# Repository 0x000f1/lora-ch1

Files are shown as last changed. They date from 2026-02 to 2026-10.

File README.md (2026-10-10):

# lora-ch1

This project is based on the ESP32-C3 microcontroller that behaves like a bridge between mobile devices and the modules. The connection is established via Bluetooth Low Energy with the phone, then sends the package over the LoRa (RFM98W/SX1278) module at 433 MHz. This combination is able to perform a full internet-independent communication between two or more devices, at a long range.

## Hardware Specification & Pinout

The current hardware is based on the ESP32-C3 microcontroller, interfaced with an RFM98W/SX1278 LoRa module, a DRV2605L haptic driver, and a BQ24075 based charging circuit.

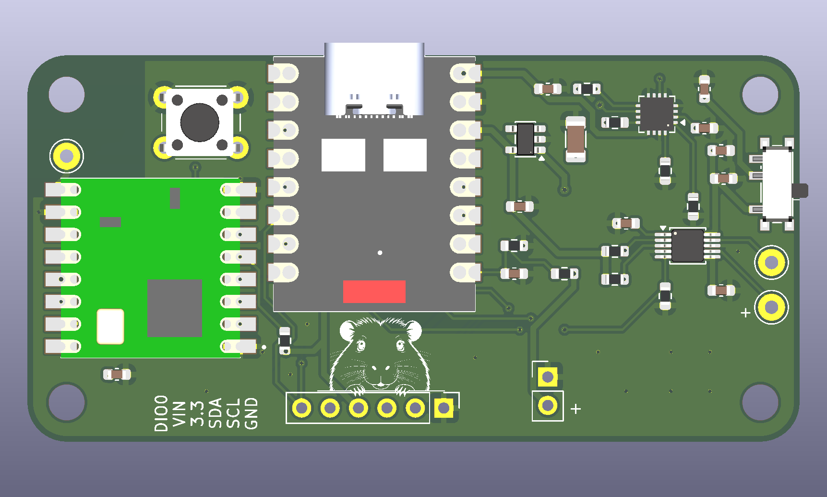
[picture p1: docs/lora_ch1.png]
PCB Layout


### ESP32-C3 GPIO Mapping

| Component | Pin Name | ESP32-C3 GPIO | Description |
| :--- | :--- | :--- | :--- |
| **LoRa (SPI)** | MISO | GPIO 5 | Master In Slave Out |
| | MOSI | GPIO 6 | Master Out Slave In |
| | NSS | GPIO 7 | Chip Select (CS) |
| | SCK | GPIO 4 | SPI Clock |
| | DIO1 | GPIO 3 | IRQ / Interrupt 1 |
| | DIO0 | GPIO 10 | IRQ / Interrupt 0 |
| | RST | GPIO 2 | LoRa Reset |
| **I2C Bus** | SDA | GPIO 8 | I2C Data (DRV2605L) |
| | SCL | GPIO 9 | I2C Clock (DRV2605L) |
| **Haptic Driver** | DRV_EN | GPIO 21 | Enable pin for DRV2605L |
| **Power / Battery** | CHRG | GPIO 20 | Charging status (BQ24075, LOW = charging) |
| | BAT_SENS | GPIO 1 | Battery Voltage ADC (ADC_11db attenuation) |
| **User Input** | BUTTON | GPIO 0 | Hardware Button (with debouncing) |

### Development Environment & Flashing
* **IDE:** **PlatformIO**
* **Board:** **`esp32-c3-devkitm-1`**

## Functions

* **Reliable Bidirectional Communication:** Transmit packages seamlessly between two or more devices. Supports public Broadcasts and private P2P messages with an Automatic Repeat Request (ARQ) mechanism. P2P messages are automatically acknowledged (ACK) and retried up to 3 times if lost in the air.
* **Fast TX & Continuous RX Architecture:** Optimized for ultra-low latency and high reliability in the prototype phase. By utilizing an optimized preamble (12 symbols), the Time on Air (ToA) is reduced to ~100-132ms (payload dependent), virtually eliminating packet collisions while ensuring zero message drops through continuous background listening. *Thread-safe FreeRTOS implementation prevents conflicts between BLE and LoRa tasks*.
* **End-to-End Encryption Support (Key Exchange):** Natively supports routing public keys for E2EE via `KEY_REQ` and `KEY_RESP` commands over the standard data characteristic. The key exchange utilizes the existing ARQ (Hardware ACK) mechanism ensuring reliable and verified key delivery between peers.
* **Offline Message Buffer:** Safely stores up to 32 incoming direct (P2P) messages in the RAM if the phone is disconnected. Upon BLE reconnection, all buffered messages are instantly pushed to the app. Public Broadcasts are ignored for offline storage to preserve memory.
* **Smart Neighbour Discovery:** Automatic heartbeat messages are sent out to advertise the active device among other users, storing the RSSI, last active timestamp, and the user's custom RGB UI color. The system automatically cleans up "dead" or out-of-range nodes after a timeout period based on the active power profile.
* **Location Sharing & Privacy:** Broadcasts the user's GPS coordinates (Latitude and Longitude) to the mesh network via Heartbeat messages. If the user disables location sharing (Privacy Mode), the system dynamically truncates the binary payload by 8 bytes to conserve precious LoRa airtime and battery life.
* **Haptic & UI Feedback:** Integrated DRV2605L haptic motor driver and hardware button with debouncing. Provides distinct physical feedback for button presses, incoming LoRa messages, and an automatic low battery warning (triggered below 15% while discharging).
* **BLE Security (Just Works):** Implements physical button-press validation to activate BLE advertising (Pairing Mode) for 60 seconds, preventing unauthorized external connections.
* **Dynamic NVS Management:** The device name, UUIDs, unique LoRa ID, haptic profile, and user preferences (Username, UI Color, Location) are generated on the first startup and safely stored in the Non-Volatile Storage (NVS).
* **Duty Cycle Monitoring:** Tracks and logs the Time on Air (ToA) and calculates the current duty cycle percentage to assist with regulatory compliance (e.g., the 10% limit on 433MHz in Europe).
* **Automated Power Management:** Supports 3 different power profiles (`BATTERY_SAVER`, `BALANCED`, `PERFORMANCE`) that dynamically scale the CPU frequency (80MHz or 160MHz) and adjust heartbeat intervals (10 min, 5 min, and 1 min respectively). The device defaults to `BATTERY_SAVER` on boot. Pressing the hardware button temporarily wakes the system into `BALANCED` mode for BLE communication.
* **Real Battery Monitoring:** Built-in hardware ADC integration calculates real battery percentage, and monitors the active charging status via the BQ24075 charging IC's open-drain output (GPIO 20).

## BLE API Documentation

The mobile app connects to the ESP32 and manages the LoRa module (and some settings).

### 1. Discovering the device (Scanning & Connection)

* **IMPORTANT (MTU Size):** The Android application **MUST** request an MTU size of 512 bytes (`requestMtu(512)`) immediately after the connection is established. Without this, Android will truncate incoming messages to 20 bytes! iOS handles this automatically.
* **Device Name:** The ESP32 starts advertising in this format `lora-ch1-XXXX` where the `XXXX` is the device's MAC address's last 2 bytes (e.g., `lora-ch1-A1B2`).
* **Dynamic UUIDs:** **IMPORTANT!** On the first start, the device generates (Version 4) UUIDs for the services and characteristics. The mobile device should use **Service Discovery** instead of hardcoded UUIDs!
* **Pairing Mode:** The device is hidden by default. Press the physical button on the device to enable Bluetooth visibility for 60 seconds.

### 2. Services and characteristics

The system advertises a single main Service, under which two characteristics (Data and Control) are located. Both characteristics support `READ`, `WRITE`, and `NOTIFY` operations.

#### A. Data Characteristic
Actual message sending and receiving takes place on this channel. The payload must follow a semicolon-separated format to support message fragmentation and direct addressing.

* **Sending (App -> LoRa):**
  * **Format 1 (Standard Message):** `TARGET_MAC;CURRENT_FRAGMENT;TOTAL_FRAGMENTS;PAYLOAD`
    * Write a String to this characteristic using the format above.
    * *Target MAC:* 8-character HEX string. Use `FFFFFFFF` to Broadcast to everyone, or a specific device's LoRa ID for a private P2P message.
    * *Example (Broadcast):* `FFFFFFFF;1;1;Hello everyone!`
    * *Example (P2P Fragmented):* `ABCD1234;1;3;This is a long me`
    * *Limitation:* The `PAYLOAD` length per BLE write should be kept around 240 bytes due to LoRa airtime limitations.
  * **Format 2 (Key Exchange):** `KEY_REQ;TARGET_MAC;PUBLIC_KEY` or `KEY_RESP;TARGET_MAC;PUBLIC_KEY`
    * Initiates or responds to an End-to-End Encryption key exchange.
    * The ESP32 automatically parses the `TARGET_MAC`, forwards the key via LoRa, and awaits a hardware ACK from the target device.
    * *Example:* `KEY_REQ;A1B2C3D4;PU8r8H3BvjiyDNbqtp12Y1LHFvhF+nJI81oWjmFqS1w=`

* **Receiving (LoRa -> App):**
  * The app must subscribe to `NOTIFY` events on this characteristic.
  * **Format 1 (Standard Data):** `SENDER_MAC;SENDER_USERNAME;COLOR_HEX;TARGET_MAC;CURRENT_FRAGMENT;TOTAL_FRAGMENTS;TIMESTAMP;RSSI;PAYLOAD`
    * The app can use the `TARGET_MAC` to determine if the received message was a public broadcast (`FFFFFFFF`) or a private P2P message.
    * `SENDER_USERNAME`: The sender's username string automatically resolved from the internal neighbor cache. Returns `Unknown` if the sender is not in the cache.
    * `COLOR_HEX`: The sender's custom UI color (e.g., `FF0000`) resolved from the cache. Defaults to `0088FF` if unknown.
    * `TIMESTAMP`: The UNIX Epoch time in seconds. If the device clock is not synced via `SET_TIM`, this value returns `0`.
    * `RSSI`: The signal strength of the received LoRa package (e.g., `-78.00`).
  * **Format 2 (Delivery Success):** `ACK_OK;TARGET_MAC`
    * Sent to the app when a previously sent P2P message (or Key Exchange) is successfully acknowledged by the receiver's hardware.
  * **Format 3 (Delivery Failed):** `ERR_TIMEOUT;TARGET_MAC`
    * Sent to the app when a P2P message fails to reach the target after maximum retries or channel collisions.
  * **Format 4 (Key Exchange):** `KEY_REQ;SENDER_MAC;PUBLIC_KEY` or `KEY_RESP;SENDER_MAC;PUBLIC_KEY`
    * Sent to the app when another device initiates or responds to a key exchange. The app can use the `SENDER_MAC` to identify the peer and complete the encryption setup.

#### B. Control Characteristic
This channel is used to query the network status and manage system preferences.

* **Commands (App -> ESP32) & Responses (via NOTIFY):**
  * `SET_TIM;UnixSeconds`
    * *Action:* Syncs the ESP32's internal RTC to the real-world UNIX epoch time (e.g., `SET_TIM;1715423000`). Must be sent immediately after connecting.
    * *Response:* `TIM_OK`
  * `SET_LOC;Latitude;Longitude`
    * *Action:* Updates the device's internal location cache with the phone's GPS coordinates to be broadcasted via LoRa (e.g., `SET_LOC;47.5316;21.6273`).
    * *Response:* `LOC_OK` or `LOC_ERR`
  * `GET_LOC`
    * *Response:* `LOC;Latitude;Longitude` (e.g., `LOC;47.531600;21.627300`).
  * `NO_LOC`
    * *Action:* Disables location sharing for privacy. Resets the coordinates to `0.0` and dynamically truncates the LoRa heartbeat payload to save bandwidth.
    * *Response:* `NO_LOC_OK`
  * `GET_NEI`
    * *Response:* `NEI|MAC;NEI_USERNAME;COLOR_HEX;RSSI;TIMESTAMP;LATITUDE;LONGITUDE|...` (e.g., `NEI|A1B2C3D4;lora-ch1-XXXX;FF0000;-45.50;32125;47.531600;21.627300|...`) or `NEI|NO_NEI` if the list is empty.
  * `GET_BAT`
    * *Response:* `BAT;Percentage;IsCharging` (e.g., `BAT;87;1` where 1 means charging, 0 means discharging).
  * `SET_USR;Username`
    * *Action:* Saves the string to NVS. Cannot contain `;` or `|` characters, and trims whitespaces. Defaults to `Guest` if empty or invalid.
    * *Response:* `USR_OK`
  * `GET_USR`
    * *Response:* `USR;Username` (Defaults to `Guest` if not set).
  * `SET_COL;HexColor`
    * *Action:* Saves the UI color HEX string to NVS (e.g., `FF0000`). Reverts to `0088FF` if the format is invalid.
    * *Response:* `COL_OK`
  * `GET_COL`
    * *Response:* `COL;HexColor` (Defaults to `0088FF` if not set).
  * `SET_PWR;ProfileName`
    * *Action:* Sets the active power profile (`BATTERY_SAVER`, `BALANCED`, `PERFORMANCE`).
    * *Response:* `PWR_OK` or `PWR_ERR` (if the profile name is invalid).
  * `GET_VIB`
    * *Response:* `VIB;{0/1}` Where 0 means haptics is off, 1 means haptics is on.
  * `SET_VIB;STATUS`
    * *Action:* `1` turns on (by default) the haptic feedback actuator, `0` turns off.
    * *Response:* `VIB_OK` means the command ran.
  * `GET_ID`
    * *Response:* `ID;LOCAL_ID` (e.g., `ID;3FFE78C0`) returns the LoRa local address.
  * `RST`
    * *Action:* Restarts the ESP, needs to reconnect after!
    * *Response:* `RST_OK`
  * `FACTORY_RESET`
    * *Action:* Erases the whole NVS partition, clears color, username, UUIDs, and all settings. The ESP restarts automatically. The LoRa MAC remains unchanged as it is generated from the hardware MAC address.
    * *Response:* `FACTORY_RESET_OK`
  * `FIND`
    * *Action:* For 5 second, spams the 750 ms Alert 100% haptic vibration.
    * *Response:* `FIND_OK`

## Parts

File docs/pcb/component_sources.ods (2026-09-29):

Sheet: Component list
 | References | Value | Footprint | Quantity | Price Aliexpress/unit | Price Hestore | Link Aliexpress | Link Hestore
1 | C1, C2, C5 | 10uF | C_0603_1608Metric | 3 |  | 21,18 |  | https://www.hestore.hu/prod_10035431.html
2 | C7, C10, C11 | 0.1uF | C_0603_1608Metric | 3 |  | 6,37 |  | https://www.hestore.hu/prod_10046165.html
3 | C12, C13, C14 | 4.7uF | C_0603_1608Metric | 3 |  | 6,93 |  | https://www.hestore.hu/prod_10037167.html
4 | C6 | 100uF | C_1206_3216Metric | 1 | 21,44 | 65,02 | https://www.aliexpress.com/item/1005010653487250.html | https://www.hestore.hu/prod_10049430.html
5 | C8 | 1.0uF | C_0603_1608Metric | 1 |  | 10,83 |  | https://www.hestore.hu/prod_10038146.html
6 | R3, R8, R11 | 100k | R_0603_1608Metric | 3 |  | 1,25 |  | https://www.hestore.hu/prod_10023891.html
7 | R4, R5 | 4.7k | R_0603_1608Metric | 2 |  | 2,62 |  | https://www.hestore.hu/prod_10023911.html
8 | R9, R10 | 1.8k | R_0603_1608Metric | 2 |  | 2,6 |  | https://www.hestore.hu/prod_10023934.html
9 | R12, R13 | 12k | R_0603_1608Metric | 2 |  | 2,19 |  | https://www.hestore.hu/prod_10023921.html
10 | R2 | 5.1k | R_0603_1608Metric | 1 |  | 1,15 |  | https://www.hestore.hu/prod_10036539.html
11 | SW1 | SW_SPDT | SW_SPDT_PCM12 | 1 | 17 |  | https://www.aliexpress.com/item/4000685483225.html
12 | MOUNT1, MOUNT2, MOUNT3, MOUNT4 | MountingHole_M3 | MountingHole_3.2mm_M3 | 4
13 | ANT1, LRAM1, LRAP1 | PINHD_1x1_Male | Pin_D1.0mm_L10.0mm_LooseFit | 3
14 | + | Conn_01x02_Pin | PinHeader_1x02_P2.54mm_Vertical | 1
15 | CHRG1 | BQ24075RGT | VQFN-16-1EP_3x3mm_P0.5mm_EP1.6x1.6mm | 1 | 235,526 |  | https://www.aliexpress.com/item/1005009095060600.html
16 | ESP1 | ESP32-C3_SUPERMINI_SMD | MODULE_ESP32-C3_SUPERMINI | 1 | 1117,56 | 1177,29 | https://www.aliexpress.com/item/100500755574.html | https://www.hestore.hu/prod_10048018.html
17 | HAPTIC1 | DRV2605LDGS | VSSOP-10_3x3mm_P0.5mm | 1 | 371,942 |  | https://www.aliexpress.com/item/1005012571855389.html
18 | INPT_BTN1 | Push_Button | SW_PUSH_6mm | 1 | 18 |  | https://www.aliexpress.com/item/1005005532747780.html
19 | LDO1 | XC6220B331MR | SOT-23-5 | 1 | 33,67 |  | https://www.aliexpress.com/item/1005003822892010.html
20 | LORA1 | RFM98W-433S2 | XCVR_RFM98W-433S2 | 1 | 1603,53 |  | https://www.aliexpress.com/item/1005003249965079.html
21 | TEST1 | PINHD_1x6_Male | PinHeader_1x06_P2.54mm_Vertical | 1 | 17,045 |  | https://www.aliexpress.com/item/4000685483225.html
22 | Mini Vibration Motor | X | X | 1 | 163,5 |  | https://www.aliexpress.com/item/1005009934713982.html
23 | Battery | X | X | 1 |  | 1519 |  | https://www.hestore.hu/prod_10048166.html
 |  |  |  |  | 2460,213 | 2816,43
 |  | USD | HUF
 | JLC Build price: | 35,43 | 11231,31
 | Ordered component total price: | 13,2515457413249 | 4200,74
 | +
 | Non passive components (And Ics) |  | 22491,6
 | Comm total (5pcs JLC order): | 33722,91
 | Comm total (/1PC JLC oirder): | 6744,582
 | Comm total (5pcs Self solder): | 26692,34
 | Comm total (/1PC seld solder): | 5338,468

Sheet: Order list
Aliexpress Order: | Price (1pcs): | Qty: | URL:
50PCS Mini 7-Pin On/Off 1P2T SPDT MSK-12C02 SMD Toggle Slide Switch For MP3 MP4 | 852,32 | 1 | https://www.aliexpress.com/item/4000685483225.html
With antenna RFM98W 433 SX1278 wireless transceiver module HopeRF ORIGINAL | 1603,73 | 5 | https://www.aliexpress.com/item/1005003249965079.html
Duties | 2758,56 | 1
Hestore order:
ESP32-C3-SUPERMINI | 1177,29 | 5 | https://www.hestore.hu/prod_10048018.html
M3-INSERT-4 | 59,61 | 20 | https://www.hestore.hu/prod_10042395.html
M3x10 SFPH | 16,57 | 20 | https://www.hestore.hu/prod_10022756.html
AKY-LP573450 | 1929,13 | 5 | https://www.hestore.hu/prod_10048166.html
VIBR-1027 | 157,48 | 5 | https://www.hestore.hu/prod_10042054.html
CAPR-6x6-WH | 25,26 | 5 | https://www.hestore.hu/prod_10042023.html
TACTS-6x6x7.3 | 27,89 | 5 | https://www.hestore.hu/prod_10042019.html
Shipping | 990 | 1
JLC order:
Plain PCB | 197,16 | 5
Build + Material | 2253,348 | 5
Duties | 4439,28 | 1
Shipping | 4181,7 | 1
Aliexpress Total cost: | 11629,53
Hestore Total cost: | 19098,85
JLC Total cost: | 20873,52
Total price: | 51601,9
Total price / 1PCS: | 10320,38
+ 3D case printing not calculated

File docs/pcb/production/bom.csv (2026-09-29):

Designator | Footprint | Quantity | Value | LCSC Part #
C1, C2, C5 | 0603 | 3 | 10uF | C19702
C10, C11, C7 | 0603 | 3 | 0.1uF | C14663
C12, C13, C14 | 0603 | 3 | 4.7uF | C19666
C6 | 1206 | 1 | 100uF | C15008
C8 | 0603 | 1 | 1.0uF | C15849
CHRG1 | VQFN-16-1EP_3x3mm_P0.5mm_EP1.6x1.6mm | 1 | BQ24075RGT | C15464
HAPTIC1 | VSSOP-10_3x3mm_P0.5mm | 1 | DRV2605LDGS | C527464
LDO1 | SOT-23-5 | 1 | XC6220B331MR | C22466451
R10, R9 | 0603 | 2 | 1.8k | C4177
R11, R3, R8 | 0603 | 3 | 100k | C25803
R12, R13 | 0603 | 2 | 12k | C22790
R2 | 0603 | 1 | 5.1k | C23186
R4, R5 | 0603 | 2 | 4.7k | C23162

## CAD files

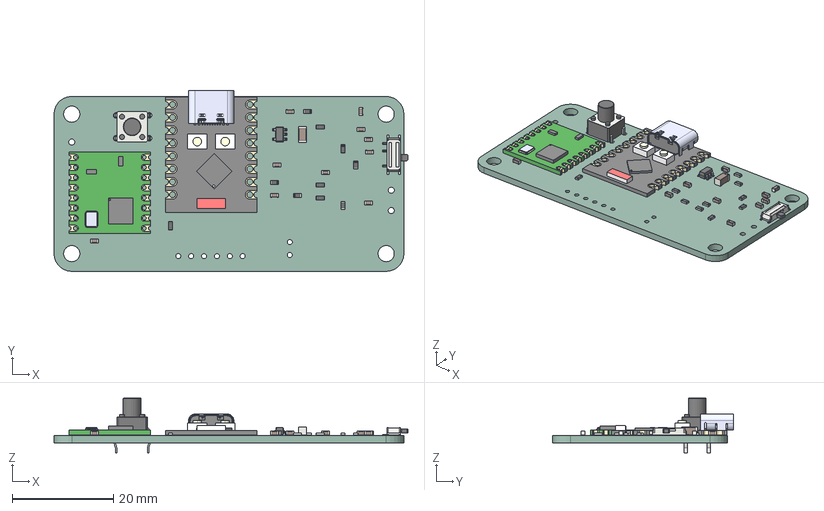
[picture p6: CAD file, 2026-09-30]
docs/pcb/lora_ch1.step
69.8 x 35.6 x 10.8 mm
R_0603_1608Metric x 10
C_0603_1608Metric x 10
RFM95W-915S2
SW_PUSH_6mm_h7.3mm
SOT-23-5
Board c3mini
USB C
components (other)^ESP32-C3 SuperMini
C_1206_3216Metric
Fusion_sp
lora_ch1-unsaved-export-1ICfBa_PCB

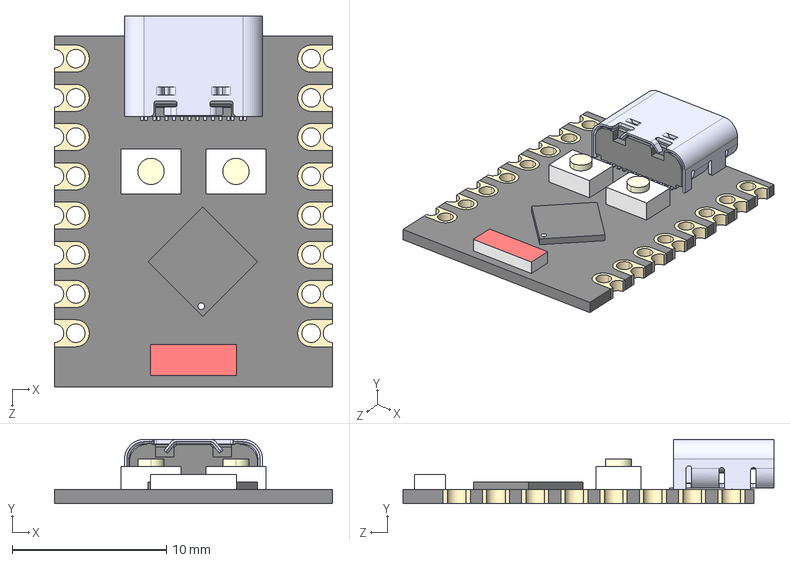
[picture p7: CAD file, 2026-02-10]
docs/pcb/PCB_Modules/ESP32-C3_SUPERMINI_SMD/ESP32-C3_SUPERMINI_SMD.step
18.0 x 4.16 x 24.0 mm
Board c3mini
USB C
components (other)^ESP32-C3 SuperMini

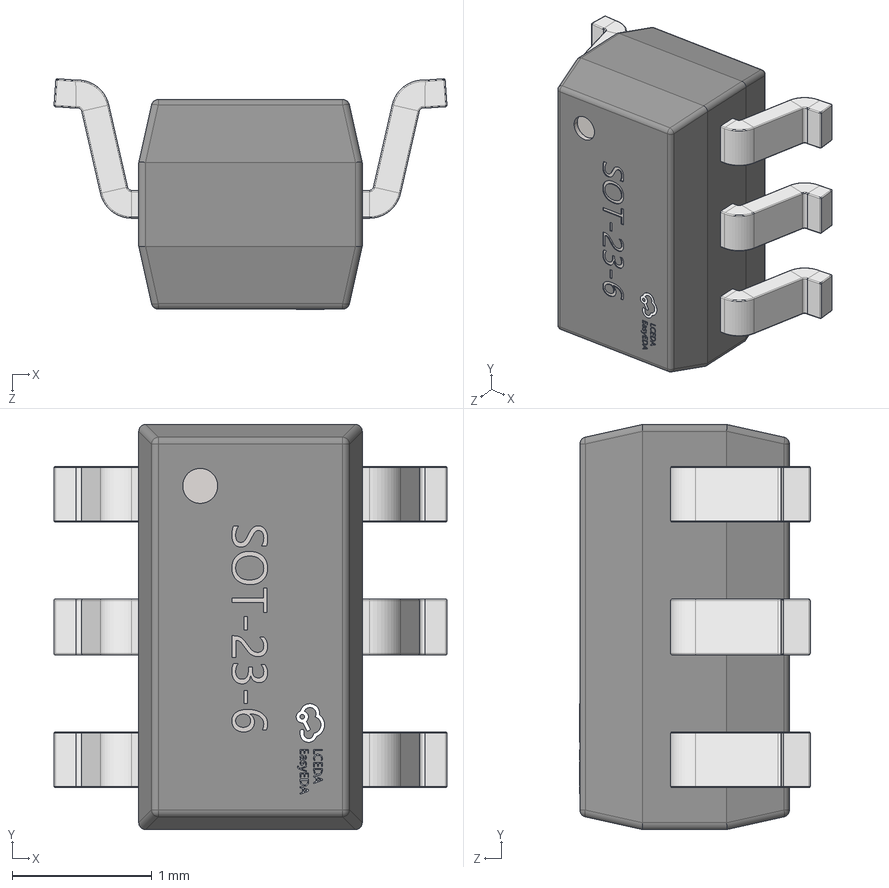
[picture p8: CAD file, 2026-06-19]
docs/pcb/PCB_Modules/FS8205A/FS8205A.step
2.81 x 2.90 x 1.65 mm

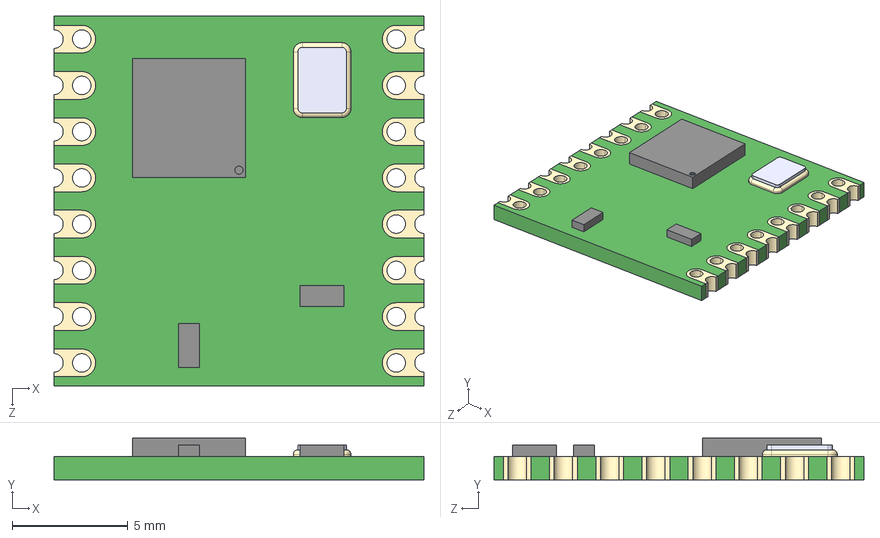
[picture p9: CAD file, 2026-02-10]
docs/pcb/PCB_Modules/RFM98W-433S2/RFM98W-433S2.step
16.0 x 1.80 x 16.0 mm

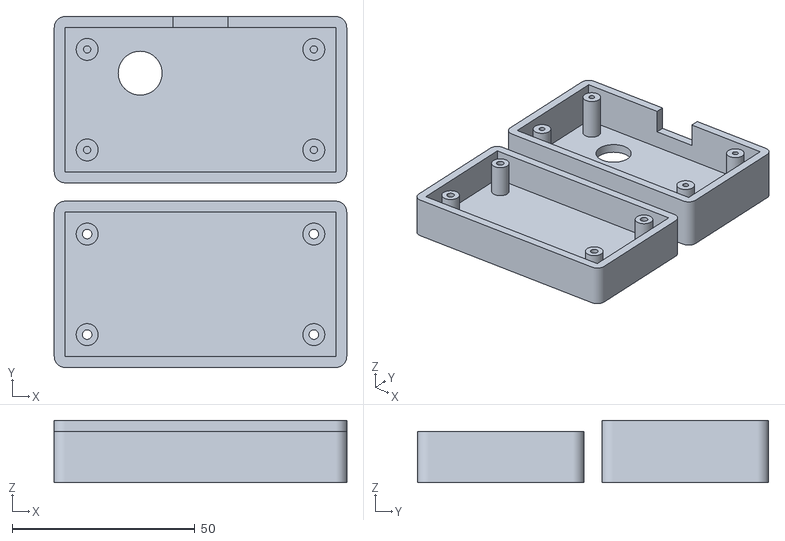
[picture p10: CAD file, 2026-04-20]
docs/print.stl
80.0 x 96.0 x 17.0

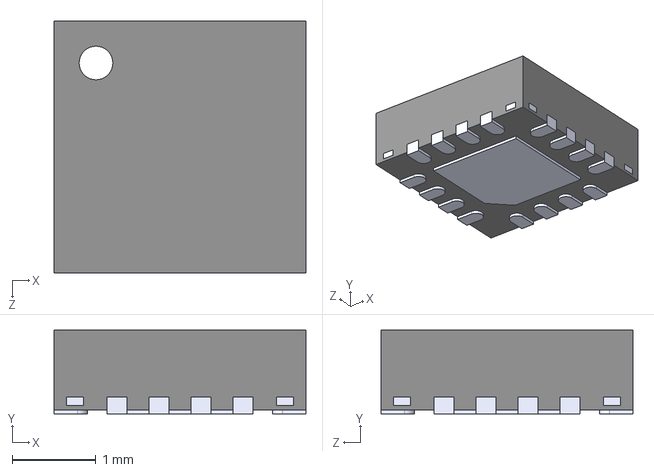
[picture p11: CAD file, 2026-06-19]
docs/pcb/PCB_Modules/BQ24075RGTR/BQ24075RGTR.step
3.00 x 1.00 x 3.00 mm

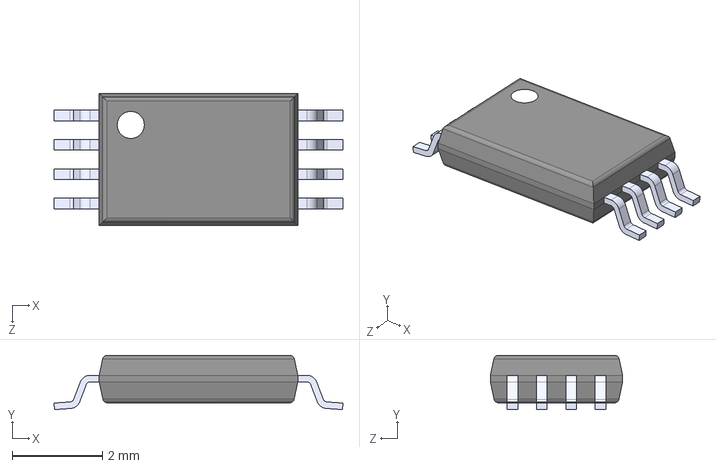
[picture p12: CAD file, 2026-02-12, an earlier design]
docs/pcb/PCB_Modules/FS8205A/_old/FS8205A.step
6.40 x 1.20 x 2.93 mm

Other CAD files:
docs/pcb/lora-ch1.step

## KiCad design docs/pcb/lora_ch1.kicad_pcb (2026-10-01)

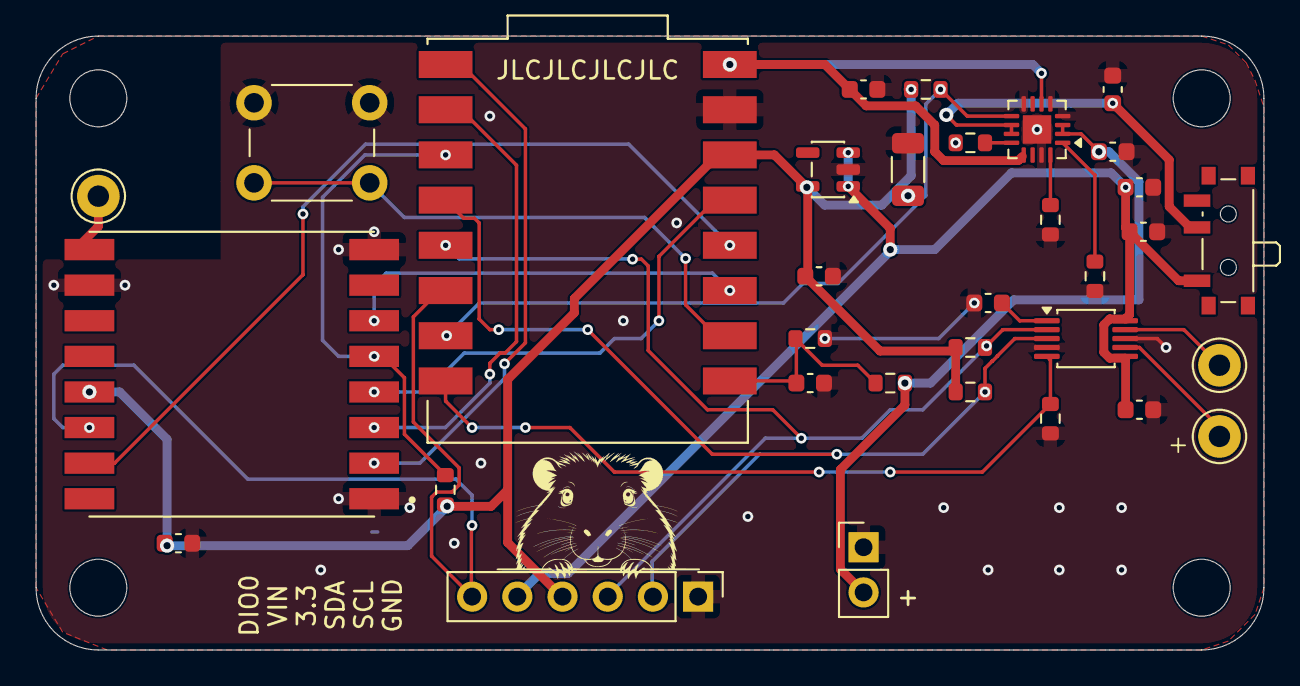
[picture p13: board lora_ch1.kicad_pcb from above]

Board: 2 copper layers, 69.0 x 34.5 mm, 37 parts (0 on the bottom side), 26 nets.

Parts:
+: Conn_01x02_Pin; PinHeader_1x02_P2.54mm_Vertical
ANT1: PINHD_1x1_Male; Pin_D1.0mm_L10.0mm_LooseFit
C1, C2, C5: 10uF; C_0603_1608Metric
C6: 100uF; C_1206_3216Metric
C7, C10, C11: 0.1uF; C_0603_1608Metric
C8: 1.0uF; C_0603_1608Metric
C12, C13, C14: 4.7uF; C_0603_1608Metric
CHRG1: BQ24075RGT; VQFN-16-1EP_3x3mm_P0.5mm_EP1.6x1.6mm
ESP1: ESP32-C3_SUPERMINI_SMD; MODULE_ESP32-C3_SUPERMINI
HAPTIC1: DRV2605LDGS; VSSOP-10_3x3mm_P0.5mm
INPT_BTN1: Push_Button; SW_PUSH_6mm
LDO1: XC6220B331MR; SOT-23-5
LORA1: RFM98W-433S2; XCVR_RFM98W-433S2
LRAM1: PINHD_1x1_Male; Pin_D1.0mm_L10.0mm_LooseFit
LRAP1: PINHD_1x1_Male; Pin_D1.0mm_L10.0mm_LooseFit
MOUNT1, MOUNT2, MOUNT3, MOUNT4: MountingHole_M3; MountingHole_3.2mm_M3
R2: 5.1k; R_0603_1608Metric
R3, R8, R11: 100k; R_0603_1608Metric
R4, R5: 4.7k; R_0603_1608Metric
R9, R10: 1.8k; R_0603_1608Metric
R12, R13: 12k; R_0603_1608Metric
SW1: SW_SPDT; SW_SPDT_PCM12
TEST1: PINHD_1x6_Male; PinHeader_1x06_P2.54mm_Vertical

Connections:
3.3V: C1.2, C6.2, C7.1, ESP1.3.3 (3V3), LDO1.5 (VOUT), LORA1.13 (3.3V), R2.1, R4.2, R5.1, R12.1, TEST1.4
ANT: ANT1.1, LORA1.9 (ANT)
BATT_PLUS: +.2, C13.1, CHRG1.2 (BAT), CHRG1.3 (BAT), R8.2
CHRG: CHRG1.9 (~CHG), ESP1.20 (GPIO20), R12.2
DRV_EN: ESP1.21 (GPIO21), HAPTIC1.5 (EN), R11.2
GND: +.1, C1.1, C2.1, C5.1, C6.1, C7.2, C8.2, C10.1, C11.2, C12.2, C13.2, C14.2, CHRG1.4 (~CE), CHRG1.5 (EN2), CHRG1.8 (VSS), CHRG1.15 (SYSOFF), CHRG1.17 (VSS), ESP1.G (GND), HAPTIC1.4 (IN/TRIG), HAPTIC1.8 (GND), INPT_BTN1.1, LDO1.2 (GND), LORA1.1 (GND), LORA1.8 (GND), LORA1.10 (GND), R3.2, R9.2, R10.1, R11.1, R13.1, TEST1.1
LORA_DIO0: ESP1.10 (GPIO10), LORA1.14 (DIO0), TEST1.6
LORA_DIO1: ESP1.3 (GPIO3), LORA1.15 (DIO1)
LORA_MISO: ESP1.5 (GPIO5), LORA1.2 (MISO)
LORA_MOSI: ESP1.6 (GPIO6), LORA1.3 (MOSI)
LORA_NSS: ESP1.7 (GPIO7), LORA1.5 (NSS), R2.2
LORA_RST: ESP1.2 (GPIO2), LORA1.6 (RESET)
LORA_SCK: ESP1.4 (GPIO4), LORA1.4 (SCK)
LRA+: HAPTIC1.7 (OUT+), LRAP1.1
LRA-: HAPTIC1.9 (OUT-), LRAM1.1
unnamed: CHRG1.12 (ILIM), R10.2
unnamed: CHRG1.16 (ISET), R9.1
unnamed: CHRG1.1 (TS), R13.2
unnamed: C10.2, ESP1.0 (GPIO0), R3.1, R8.1
unnamed: ESP1.1 (GPIO1), INPT_BTN1.2
unnamed: C8.1, HAPTIC1.1 (REG)
SCL: ESP1.9 (GPIO9), HAPTIC1.2 (SCL), R5.2, TEST1.3
SDA: ESP1.8 (GPIO8), HAPTIC1.3 (SDA), R4.1, TEST1.2
SYS_PWR: C14.1, CHRG1.10 (OUT), CHRG1.11 (OUT), SW1.2 (B)
V_IN: C2.2, C5.2, C11.1, HAPTIC1.6 (VDD/NC), HAPTIC1.10 (VDD), LDO1.1 (VIN), LDO1.3 (CE), SW1.1 (A), TEST1.5
V_USB: C12.1, CHRG1.6 (EN1), CHRG1.13 (IN), ESP1.5V

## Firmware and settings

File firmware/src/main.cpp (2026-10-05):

#include <Arduino.h>
#include "utils/log_helper.h"
#include "managers/ble/ble.h"
#include "managers/system/system_manager.h"
#include "managers/lora/lora.h"
#include "drivers/ui/haptic.h"
#include "drivers/ui/button.h"

#define TAG "MAIN"

TaskHandle_t mainTaskHandle = NULL;

void setup() {
    Serial.begin(115200);
    
    mainTaskHandle = xTaskGetCurrentTaskHandle();
    LoRaManager::setMainTaskHandle(mainTaskHandle);

    BatteryManager::setupBattery();
    // Set the default power profile to BATTERY_SAVER until button pressed
    SystemManager::setPowerProfile(PowerProfile::BATTERY_SAVER);
    SystemManager::setupNVS();
    BLEManager::setupBLE();

    int loraState = LoRaManager::setupLoRa();
    if (loraState != 0) {
        LOG_E(TAG, "LoRa setup failed: %d", loraState);
    }

    HapticManager::setupHaptic();
    ButtonManager::setupButton();
}

void handleHILCommands() {
    if (Serial.available()) {
        String cmd = Serial.readStringUntil('\n');
        cmd.trim();
        
        if (cmd == "PING") {
            Serial.println("PONG");
        }
        if (cmd == "TEST_HAP") {
            LOG_I(TAG, "HIL: Haptic test triggered");
            HapticManager::playEffect(7);
            Serial.println("UART:haptest_ok");
        } 
        else if (cmd == "TEST_ADV") {
            LOG_I(TAG, "HIL: BLE Advertising triggered");
            BLEManager::startPairingMode();
            Serial.println("UART:advtest_ok");
        } 
        else if (cmd == "TEST_TX") {
            LOG_I(TAG, "HIL: LoRa TX triggered");
            uint8_t payload[] = "HIL_STRESS_TEST";
            LoRaManager::queueMessage(payload, sizeof(payload), BROADCAST_ADDRESS, 1, 1);
            Serial.println("UART:txtest_ok");
        } 
        else if (cmd.startsWith("SET_PWR;")) {
            int pwr = cmd.substring(8).toInt();
            SystemManager::setPowerProfile((PowerProfile)pwr);
            Serial.println("UART:pwr_ok");
        }
        else if (cmd == "GET_BAT") {
            uint8_t batLevel = BatteryManager::getBatteryPercentage();
            Serial.printf("UART:BAT;%d\n", batLevel);
        }
    }
}

void loop() {
    BLEManager::handleFlags();
    LoRaManager::handleFlags();
    ButtonManager::handleButton();
    BatteryManager::handleBattery();
    // handleHILCommands();
    ulTaskNotifyTake(pdTRUE, pdMS_TO_TICKS(10));
}

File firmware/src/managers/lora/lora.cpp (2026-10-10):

#include "lora.h"
#include "utils/log_helper.h"
#include "managers/ble/ble.h"
#include "managers/system/system_manager.h"
#include "drivers/ui/haptic.h"
#include <SPI.h>
#include <RadioLib.h>
#include <time.h>

#define TAG "LORA"
#define BAND 433.175
#define BANDWIDTH 125.0
#define SPREADING_FACTOR 8
#define CODING_RATE 5
#define SYNC_WORD 0x12
#define POWER 10
#define PREAMBLE_LENGTH 12 // 1 symbol: 2.048ms, 12 symbol ~ 25ms)
#define GAIN 0

#define LORA_SCK  4
#define LORA_MISO 5
#define LORA_MOSI 6
#define LORA_NSS  7
#define LORA_RST  2
#define LORA_DIO0 10
#define LORA_DIO1 3

// Static variables (Heartbeat, sequence number, duty cycle stats, neighbors)
TaskHandle_t LoRaManager::mainTaskHandle = NULL;
TimerHandle_t LoRaManager::heartbeatTimer = nullptr;
volatile bool LoRaManager::heartbeatPending = false;
uint8_t LoRaManager::currentSequenceNumber = 0; // Initialize sequence number
uint32_t LoRaManager::totalAirTimeMs = 0;
unsigned long LoRaManager::statsStartTime = 0;
unsigned long LoRaManager::nextTxAllowedMillis = 0;
DiscoveryInfo LoRaManager::neighbors[MAX_NEIGHBORS];
uint8_t LoRaManager::neighborCount = 0;

TimerHandle_t LoRaManager::ackTimer = nullptr;
volatile bool LoRaManager::ackTimeoutPending = false;
uint8_t LoRaManager::retryCount = 0;
const uint8_t LoRaManager::MAX_RETRIES = 3; // Max 3 retries before drop the package
volatile bool LoRaManager::waitingForAck = false;

uint8_t LoRaManager::lastPayload[
    PAYLOAD_SIZE - sizeof(PackageHeader)
];

size_t LoRaManager::lastPayloadLength = 0;
uint32_t LoRaManager::lastTargetAddress = 0;
uint8_t LoRaManager::lastCurrentFragment = 0;
uint8_t LoRaManager::lastTotalFragment = 0;
uint8_t LoRaManager::lastSequenceNumber = 0;

QueueHandle_t LoRaManager::txQueue = nullptr;

uint32_t LoRaManager::heartbeatIntervalSeconds = 300;

LoRaManager::ReceivedPacket
    LoRaManager::receivedCache[MAX_RECEIVED_CACHE];

uint8_t LoRaManager::receivedCacheCount = 0;

// CAD variables
// TimerHandle_t LoRaManager::cadRxTimer = nullptr;
// volatile bool LoRaManager::cadCheckPending = false;
// TimerHandle_t LoRaManager::rxTimeoutTimer = nullptr;
// volatile bool LoRaManager::rxTimeoutPending = false;

// void LoRaManager::cadRxTimerCallback(TimerHandle_t xTimer) {
//     cadCheckPending = true; 
// }
// void LoRaManager::rxTimeoutTimerCallback(TimerHandle_t xTimer) {
//     rxTimeoutPending = true;
// }

SPIClass loraSPI(FSPI); // FSPI = SPI2 | Use the FSPI for custom pin configuration
SX1278 loraModule = new Module(LORA_NSS, LORA_DIO0, LORA_RST, LORA_DIO1, loraSPI);

volatile bool actionFlag = false; // Interrupt flag to show receive/transmit events.
bool isTransmitting = false;      // Current state: true = waiting for transmission to finish, false = waiting for package.
// bool isScanning = false;          // true = CAD scanning in the background

// Interrupt callback stored in RAM to ensure fast access.
void IRAM_ATTR LoRaManager::setFlag() {
    actionFlag = true;

    // FreeRTOS task wake up from interrupt (instantly wake up on received)
    BaseType_t xHigherPriorityTaskWoken = pdFALSE;
    if (mainTaskHandle != NULL) {
        vTaskNotifyGiveFromISR(mainTaskHandle, &xHigherPriorityTaskWoken);
        if (xHigherPriorityTaskWoken) {
            portYIELD_FROM_ISR(); // Context switch, if required
        }
    }
}

int LoRaManager::setupLoRa() {
    txQueue = xQueueCreate(
        8,
        sizeof(TxMessage)
    );

    if (txQueue == nullptr) {
        LOG_E(TAG, "Failed to create TX queue");
        return -1;
    }

    loraSPI.begin(LORA_SCK, LORA_MISO, LORA_MOSI, LORA_NSS);
    statsStartTime = millis(); // Start the timer for duty cycle statistics.

    // Timers
    ackTimer = xTimerCreate("ackTimer", pdMS_TO_TICKS(2000), pdFALSE, nullptr, ackTimerCallback);
    // CAD Timer
    // cadRxTimer = xTimerCreate("cadRxTimer", pdMS_TO_TICKS(30), pdTRUE, nullptr, cadRxTimerCallback);
    // rxTimeoutTimer = xTimerCreate("rxTimeoutTimer", pdMS_TO_TICKS(1500), pdFALSE, nullptr, rxTimeoutTimerCallback); // If the CAD alert was false
    if (ackTimer == nullptr) {
        LOG_E(TAG, "Failed to create ACK timer");
        return -2;
    }

    LOG_I(TAG, "Initializing SX1278...");
    int state = loraModule.begin(BAND, BANDWIDTH, SPREADING_FACTOR, CODING_RATE, SYNC_WORD, POWER, PREAMBLE_LENGTH, GAIN);
    if (state != RADIOLIB_ERR_NONE) {
        LOG_E(TAG, "Setup failed, code: %d", state);
        return state;
    }

    // Register callbacks (Receive and Transmit completion).
    loraModule.setPacketReceivedAction(setFlag);
    loraModule.setPacketSentAction(setFlag);
    loraModule.setChannelScanAction(setFlag);

    startReceive(); // Start listening for incoming messages.
    return 0;
}

void LoRaManager::startReceive() {
    // loraModule.standby();
    isTransmitting = false;
    // isScanning = false;

    int state = loraModule.startReceive();
    if (state != RADIOLIB_ERR_NONE) {
        LOG_E(TAG, "Failed to start receive: %d", state);
    }
    // loraModule.sleep();

    // if (cadRxTimer != nullptr) xTimerStart(cadRxTimer, 0); // Start the CAD cycle
}

void LoRaManager::queueMessage(uint8_t* data, size_t length, uint32_t targetAddress, uint8_t currentFragment, uint8_t totalFragment) {
    constexpr size_t MAX_DATA_LENGTH = PAYLOAD_SIZE - sizeof(PackageHeader);

    if (data == nullptr && length > 0) {
        LOG_E(TAG, "queueMessage: NULL data");
        return;
    }

    if (length > MAX_DATA_LENGTH) {
        LOG_W(TAG, "Payload too large: %u > %u", (unsigned)length, (unsigned)MAX_DATA_LENGTH);
        return;
    }

    if (txQueue == nullptr) {
        LOG_E(TAG, "TX queue not initialized");
        return;
    }

    TxMessage message{};

    message.length = length;
    message.targetAddress = targetAddress;
    message.currentFragment = currentFragment;
    message.totalFragment = totalFragment;

    if (length > 0) {
        memcpy(message.data, data, length);
    }

    if (xQueueSend(txQueue, &message, 0) != pdPASS) {
        LOG_W(TAG,"TX queue full - message dropped");
    }
}
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

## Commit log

2026-02-05 Default directories, frame of the whole project.
2026-02-10 PCB design files added.
    [ESP32-C3_SUPERMINI_TH.step, RFM98W-433S2.step, lora_ch1.kicad_pcb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]
2026-02-11 PCB schematic update, charging function added.
    [lora_ch1.kicad_pcb, lora_ch1.kicad_sch]
2026-02-12 LORA Pin update to keep boot sequence stable.
2026-02-12 PCB schematic finished.
    [FS8205A.step, lora_ch1.kicad_pcb, lora_ch1.kicad_sch]
2026-02-17 PCB design finished.
    [lora_ch1.kicad_pcb, lora_ch1.kicad_sch]
2026-02-18 PCB ready to print.
    [ESP32-C3_SUPERMINI_SMD.step, lora_ch1.kicad_pcb, lora_ch1.kicad_sch]
2026-02-22 Haptic driver setup begin (DRV2605L)
2026-02-26 Power profiles added (BATTERY_SAVER, BALANCED, PERFORMANCE)
2026-02-26 Heartbeat (Device discovery function added) with variable advertising rate.
2026-03-02 Direct addressing resolved, and the neighbor removing loop moved to execute with heartbeat send function.
    [lora.cpp]
2026-03-04 Button press function added. (Currently just handles it and plays a haptic effect.)
2026-03-06 Implement secure BLE Pairing Mode (Just Works) with hardware button
2026-03-06 LoRa CAD (Listen Before Talk) implementation, and resolved -24 TX error.
    [lora.cpp]
2026-03-07 CAD hotfix, thread-safe queued message send function called on BLE characteristic write. README update.
2026-03-13 Battery management functions added, can be changed on control characteristics with "SET_PWR;<PROFILE>" string.
2026-03-13 Resolve LoRa CAD blocking issue and implement async TX/RX
    [lora.cpp, main.cpp]
2026-03-16 BLE completely turned off while disconnected, stops advertising and 'sleeps' at ~20mA
2026-04-16 CAD function ignored on SX1278, listening always without CAD implemented.
2026-04-16 Revert "CAD function ignored on SX1278, listening always without CAD implemented."
    This reverts commit 7ddfc94e589f47eaf240261d2b1e9211bfd936e6.
    [lora.cpp]
2026-04-17 Reapply "CAD function ignored on SX1278, listening always without CAD implemented."
    This reverts commit ba692f1b1611bafccdbb9f819575b8c408437e7b.
    [lora.cpp]
2026-04-17 refactor: removed CAD for Fast TX architecture, expanded BLE API (NVS user config) & fixed DIO0 interrupt bug
    [battery.cpp]
2026-04-20 Comment fix, .step sample added for printing + consumption table generated (without energy management)
    [consumption.ods, lora-ch1.step, print.stl]
2026-06-19 PCB rework, added DIO1 connection to GPIO3, changed DIO0 location to GPIO2. Changed the charging controller from TP4056 to BQ24075RGT.
    [BQ24075RGTR.step, FS8205A.step, bom.csv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]
2026-07-03 LoRa pin changes to keep up with the new PCB, GET_BAT ADC read resolved, isCharging status added. (Format: BAT;PERCENT;IS_CHARGING)
    [battery.cpp, lora.cpp, main.cpp]
2026-07-03 Fixing the log location of battery status.
    [battery.cpp]
2026-07-05 Resolved BLE auto disable on disconnect, reduced standby power consumption.
2026-07-05 LoRa CAD resolved, reduced consumption.
    [lora.cpp]
2026-07-06 Comment fix on lora.cpp
    [lora.cpp]
2026-07-08 Revert CAD mechanics to improve stability.
    [lora.cpp]
2026-07-10 Finished v1.0 firmware. Replaced CAD to Continuous RX to ensure short distance communication stability. Implemented FreeRTOS interrupt wake up on RX. Adjusted Heartbeat interval and extended timeout.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
    [lora.cpp, main.cpp]
2026-07-12 Finished v1.1 firmware. Confirmed the 12-symbol preamble hardware-software integration. Validated the offline message buffer (up to 32 P2P messages) and automated BLE push mechanism. Ensured proper U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
    [lora.cpp]
2026-07-15 PCB rework V1.3 Removed BMS1 (FS8205A), BATTP1 (DW01A) and connected BATT- to GND. Resolved the conflict between battery and built in LDO.
    [lora_ch1.kicad_pcb, lora_ch1.kicad_sch]
2026-09-29 SET_VIB, GET_VIB added. Editable with control char. write to change the haptics profile.
    [bom.csv, component_sources.ods, designators.csv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]
2026-09-29 Haptic warning on critically low battery (<15%)
2026-09-29 Ignore broadcast message if there is no connected devices.
2026-09-29 Private page, Disconnect button, Get battery level, Get neighbors
2026-09-30 Default username edited to Device Name (lora-ch1-XXXX)
2026-09-30 No haptics on client connected, the app will notify.
    [lora_ch1.kicad_pcb, lora_ch1.step]
2026-09-30 NEI timestamp fix, changed form millis() to actual UNIX timestamp if stored.
    [lora.cpp]
2026-10-01 Fixed performance issue when switching pages, error handling for ble streams
2026-10-01 refactor(lora): reduce packet header and fix TX reliability
    [lora.cpp, main.cpp]
2026-10-01 On button press don't send the Heartbeat message
2026-10-01 (back)Button press: Send heartbeat (new)display color on message receive in BLE characteristic
2026-10-01 PCB image & footprint updates
    [lora_ch1.kicad_pcb]
2026-10-02 Heartbeat power profile times updated
2026-10-05 Battery safe range modified to 3.4v-4.2v (Below unstable BLE connection) HIL UART Commands implemented in main
    [battery.cpp, main.cpp]
2026-10-05 Display peer device color
2026-10-05 Charger plugged in haptic feedback
2026-10-05 Low battery new haptic effect
2026-10-06 Database insertion for incoming messages moved to ble-service
2026-10-06 GPS coordinates implemented, now able to set, clear, turn off location. (%f mutex error handled)
    [lora.cpp]
2026-10-08 Replaced app theme with dark mode. New UI for settings. Funcional find, restart, and reset buttons.
2026-10-08 Username filter
2026-10-09 Battery indicator updated
2026-10-11 Disconnect from device before connecting to a new one
2026-10-11 Remove device from peer list if it was previously connected
2026-10-14 ERM to LRA library changed for haptic driver.
2026-10-16 Fixed GET_BAT timing out after device restart, added color_utils
2026-10-16 Get battery status after connecting
2026-10-16 Battery timer changed from 5 seconds to 20
2026-10-17 Permission denied exception handled on device discovery
2026-10-17 feat(lora): implement dynamic ACK timeout and protocol optimizations
    - Implemented dynamic ACK timeout based on ToA, 10% duty cycle wait, and ACK ToA.
    - Added fragment timestamp synchronization (all fragments of a message now share the same UNIX timestamp).
    - Added txQueue purging for remaining fragments when MAX_RETRIES is reached to save airtime.
    - Fixed neighbor 'lastSeenMillis' starvation during active P2P chatting (now updates on all valid packets).
    - Optimized SPI bus usage by caching the RSSI value during packet processing.
    - Updated README.md to reflect new dynamic ACK and timestamp grouping behaviors.
2026-10-18 500 to 1500ms before haptic driver ENA off.
2026-10-21 Fixed stuck BLE streams when switching devices
2026-10-21 Fixed broadcast notifications switch assigned to private notifications
